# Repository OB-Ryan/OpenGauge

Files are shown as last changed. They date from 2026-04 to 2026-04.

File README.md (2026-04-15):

# OpenGauge
OpenGauge is an ESP32-based OBD-II CAN bus interface for reading real-time vehicle telemetry such as speed, engine RPM, and coolant temperature using an MCP2551 CAN transceiver.

## Components and Materials
- ESP32 Microcontroller
- 12V to 5V Buck Converter
- MCP2551 CAN Transceiver
- 5V 3.3V Bidirectional Logic Shifter
- 16x2 I2C LCD Display
- OBD-II Harness
- Push Button
- Breadboard
- Jumperwires
- Multimeter

## Circuit
### OBD-II Harness
The OBD-II harness will plug into the vehicle, and provide a means for interfacing with the vehicle ECU. The pins of interest are CAN High, CAN Low, Chasis ground, Signal ground, and +12V battery power. Double check the harness connetions with the corresponding pin numbers using a miltimeter.

### ESP32 and Components
This project uses an ESP32 development board as the primary microcontroller, connected to three 3 components:

CAN Bus Interface: The ESP32's built-in TWAI (Two-Wire Automotive Interface) is used for OBD-II communication. GPIO 4 (RX) and GPIO 5 (TX) connect to a MCP2551 CAN transceiver module, which interfaces with the vehicle's OBD-II diagnostic port. A 3.3V-5V logic shifter is placed between the transceiver and EPS32, to step up/down the voltage logic accordinly.

Display: A 16×2 LCD display (I2C address 0x27) connects via the ESP32's I2C bus to display the currently selected sensor reading and its value.

User Input: A momentary push button connected to GPIO 23, and ground (with internal pull-up enabled) allows the user to cycle through available sensor modes.

### Pictorial Schematic
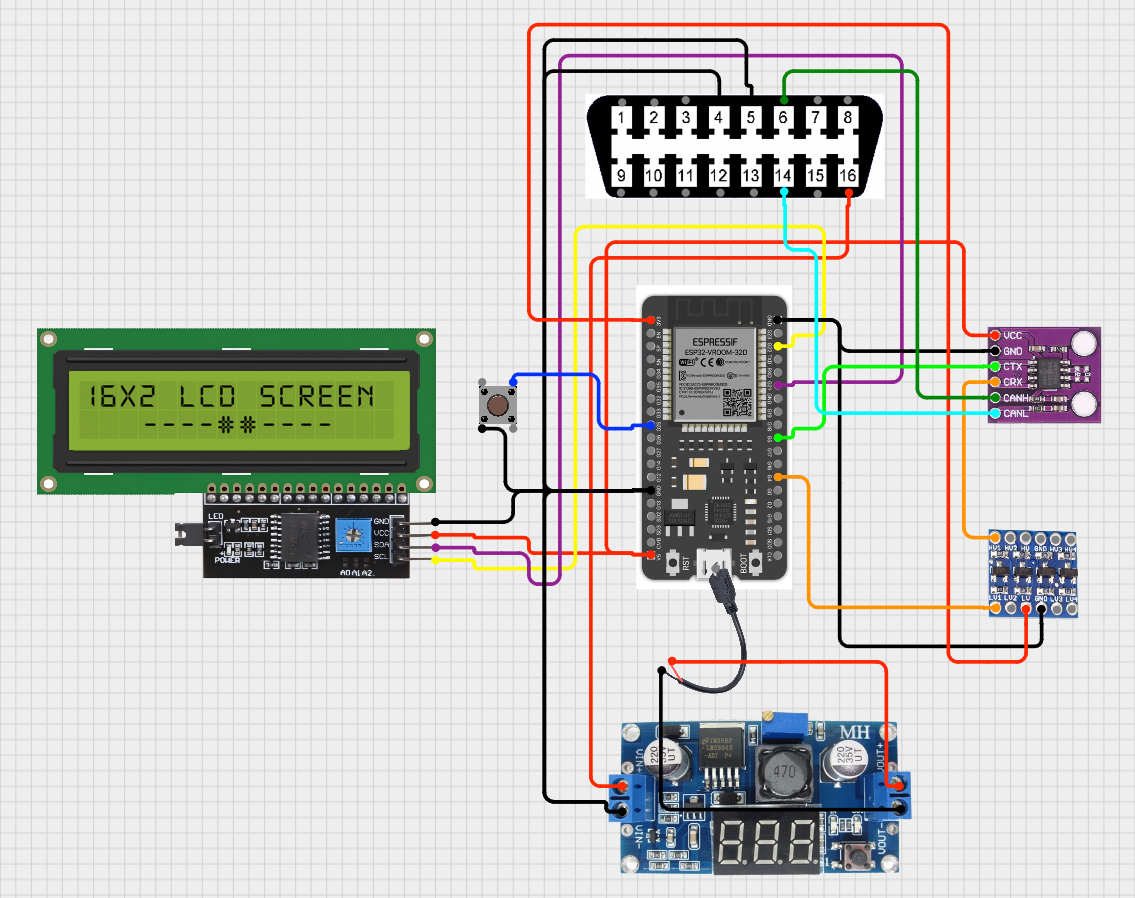
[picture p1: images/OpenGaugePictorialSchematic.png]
Pictorial Schematic


## Code
This project is implemented in Arduino C++ with PlatformIO for an ESP32-based OBD-II gauge. At a high level, main.cpp initializes the CAN interface and LCD display, then runs a simple state polling loop (IDLE and WAITING states) to request and display live vehicle data.

Using the [ESP32-TWAI-CAN library](https://github.com/handmade0octopus/ESP32-TWAI-CAN), the firmware periodically sends OBD-II Mode 01 requests for the currently selected PID. A push button cycles through these display modes, and the LCD is updated with the latest valid reading. Currently, the requested PIDs allow display modes of engine load, engine RPM, vehicle speed, coolant temperature, intake temperature, oil temperature, and fuel pressure.

The runtime logic is designed to be bus-friendly and resilient. Requests are limited to one every 1.2 seconds to avoid ECU-lockout, responses are validated by CAN ID/mode/PID before use, and timeout handling returns the system to request mode without blocking. If repeated transmit failures occur, CAN is marked offline and the code periodically attempts automatic bus recovery.

## PCB
A custom PCB has been designed to provide a more integrated solution. The board features soldered pads for the ESP32 microcontroller, MCP2551 CAN transceiver, logic level shifter, and user button.

Screw terminals provide connectors for the OBD-II diagnostic harness and I2C LCD display, and integrated mounting holes allow the buck converter and LCD to be secured directly to the board for a clean, compact layout. This design enables quick assembly for a more permanent design of this project.
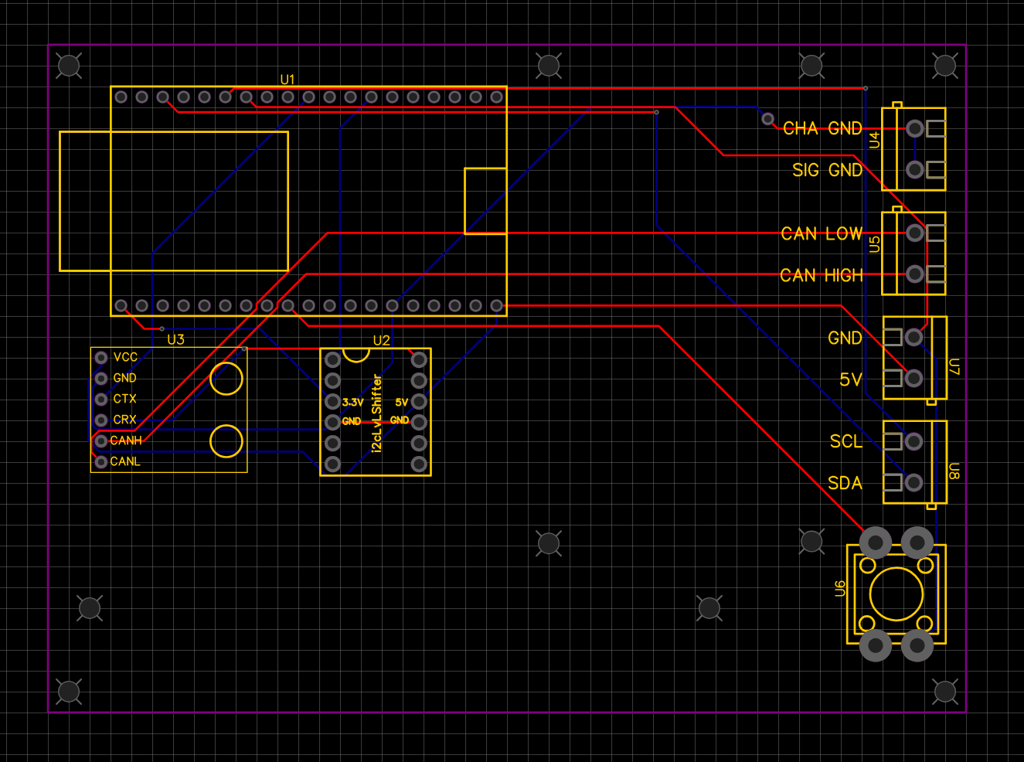
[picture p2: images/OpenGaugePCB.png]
PCB


PCB fabrication and source files are included in the `PCB/` directory:
- EasyEDA source: `PCB/OpenGauge.json`
- Manufacturing files: `PCB/OpenGauge_Gerber/`
- Ordering notes: `PCB/README.md`

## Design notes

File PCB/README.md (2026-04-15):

# OpenGauge PCB Files

This folder contains both the editable EasyEDA source and the manufacturing outputs needed to order boards.

## Contents
- `OpenGauge.json`: EasyEDA source file (edit this file for schematic/PCB changes)
- `OpenGauge_Gerber/`: Gerber and drill files for PCB fabrication

## Ordering a PCB
1. Zip the full `OpenGauge_Gerber/` folder.
2. Upload the zip to your PCB manufacturer (for example, JLCPCB, PCBWay, or OSH Park).
3. Verify board outline and drill preview before placing the order.

## Notes
- Keep all files inside `OpenGauge_Gerber/` together.
- Do not delete drill files (`.DRL`) or outline/layer files (`.GKO`, `.GTL`, `.GBL`, etc.).
- Regenerate and replace the Gerber folder any time the design in `OpenGauge.json` changes.

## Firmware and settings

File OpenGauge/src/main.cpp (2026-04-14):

#include <Arduino.h>
#include <ESP32-TWAI-CAN.hpp>
#include <LiquidCrystal_I2C.h>

/*
OBDII Reference: https://en.wikipedia.org/wiki/OBD-II_PIDs

    MODES
01  Show current data
02  Show freeze frame data
03  Show stored Diag trouble codes
04  Clear diag trouble codes and stored values
05  Test results, o2 sensor minitoring non-CAN
06  Test results, other component/system monitoring CAN
07  Show pending diag trouble codes
08  Control operation of on-board component/system
09  Request vehicle info
0A  Permanent Diag trouble codes

    STANDARD PIDs OF INTEREST
04  Calculated engine load (%). Formula: (A * 100) / 255
05  Engine coolant temperature (C). Formula: (A - 40)
10  Fuel pressure (kPa). Formula: A * 3
12  Engine speed (RPM). Formula: ((256A + B) / 4)
13  Vehicle speed (km/h). Formula: (A)
15  Intake air temperature (C). Formula: (A - 40)
92  Engine oil temperature (C). Formula: (A - 40)
*/

// PIDs
#define LOAD        4
#define COOLANT_TMP 5
#define FUEL_PRESS  10
#define RPM         12
#define SPEED       13
#define AIR_TMP     15
#define OIL_TMP     92

// Pin definitions and constants
#define CAN_TX		5               // CAN TX GPIO
#define CAN_RX		4               // CAN RX GPIO
#define I2C_ADDR  0x27            // I2C LCD addr
#define LCD_LINES 2               // 16x2 LCD screen size
#define LCD_LEN   16
#define BUTTON    23              // Push-button on pin 23
#define OBDII_RESPONSE_ID_MIN      0x7E8
#define OBDII_RESPONSE_ID_MAX      0x7EF
#define OBDII_REQUEST_IDENTIFIER   0x7DF

LiquidCrystal_I2C lcd(I2C_ADDR, 16, 2);
CanFrame rxFrame;
char buf[LCD_LEN + 1];  // Buffer to hold strings to print on LCD
int mode = 0;           // Current sensor mode
int modes[] = {LOAD, COOLANT_TMP, FUEL_PRESS, RPM, SPEED, AIR_TMP, OIL_TMP};
int mode_index = 0;
int num_modes = sizeof(modes) / sizeof(modes[0]);

// Sensor reading vars
int latest_load = -1;
int latest_coolant_temp = -1;
float latest_fuel_pressure = -1;
int latest_rpm = -1;
float latest_speed = -1;
int latest_air_temp = -1;
int latest_oil_temp = -1;

// State management
enum State {IDLE, WAITING};
State state = IDLE;
unsigned long request_sent_time = 0;
const unsigned long timeout = 1000;              // 1 second CAN request timeout
unsigned long last_obd_request_time = 0;
const unsigned long obd_request_interval = 1200; // 1.2 second between OBD requests (allow margin of error)

unsigned long last_invalid_frame_log_time = 0;
bool can_online = false;
int consecutive_tx_failures = 0;
const int failure_threshold = 10;
unsigned long last_recovery_attempt_time = 0;
const unsigned long recovery_interval = 3000;


bool is_obd_response_identifier(uint32_t identifier) {
  return identifier >= OBDII_RESPONSE_ID_MIN && identifier <= OBDII_RESPONSE_ID_MAX;
}

bool is_valid_obd_response(const CanFrame &frame, uint8_t expected_pid, uint8_t min_dlc) {
  return !frame.extd &&
    is_obd_response_identifier(frame.identifier) &&
    frame.data_length_code >= min_dlc &&
    frame.data[1] == 0x41 &&
    frame.data[2] == expected_pid;
}

void log_frame_brief(const CanFrame &frame) {
  Serial.printf("RX id=0x%03lX dlc=%d data=%02X %02X %02X %02X %02X %02X %02X %02X\n",
    frame.identifier,
    frame.data_length_code,
    frame.data[0],
    frame.data[1],
    frame.data[2],
    frame.data[3],
    frame.data[4],
    frame.data[5],
    frame.data[6],
    frame.data[7]
  );
}

bool begin_can() {
  bool success = ESP32Can.begin(ESP32Can.convertSpeed(500), CAN_TX, CAN_RX, 10, 10);
  if (success) {
    Serial.println("CAN bus started!");
  } else {
    Serial.println("CAN bus failed!");
  }
  return success;
}

bool send_obd_frame(uint8_t obdId) {
	CanFrame obdFrame = { 0 };
  obdFrame.identifier = OBDII_REQUEST_IDENTIFIER;
	obdFrame.extd = 0;
	obdFrame.data_length_code = 8;
	obdFrame.data[0] = 2;
	obdFrame.data[1] = 1;
	obdFrame.data[2] = obdId;
  
  // Padding of 0xAA to avoid bit surfing
  obdFrame.data[3] = 0xAA;
  obdFrame.data[4] = 0xAA;
  obdFrame.data[5] = 0xAA;
  obdFrame.data[6] = 0xAA;
	obdFrame.data[7] = 0xAA;

  // Accepts both pointers and references 
  bool tx_ok = ESP32Can.writeFrame(obdFrame, 25);
  if (!tx_ok) {
    Serial.printf("TX failed for PID 0x%02X\n", obdId);
    return false;
  } else {
    Serial.printf("TX PID 0x%02X on 0x%03X\n", obdId, OBDII_REQUEST_IDENTIFIER);
    return true;
  }
}

void init_lcd() {
  lcd.init();
  lcd.backlight();
  lcd.clear();
  lcd.setCursor(0, 0);
  lcd.print("OBD2 CAN Ready");
}

void lcd_clear_line(int line) {
  if (line != 0 && line != 1) {
    Serial.println("ERROR    |    lcd_clear_line: line not valid for 16x2 LCD");
    return;
  }

  lcd.setCursor(0, line);
  for (int i = 0; i < LCD_LEN; i++) {
    lcd.print(" ");
  }
}

void lcd_write(int line, const char* message) {
  if (line != 0 && line != 1) {
    Serial.println("ERROR    |    lcd_write: line not valid for 16x2 LCD");
    return;
  }

  if (strlen(message) > LCD_LEN) {
    Serial.println("ERROR    |    lcd_write: message too long for 16x2 LCD");
    return;
  }

  lcd_clear_line(line);
  lcd.setCursor(0, line);
  lcd.print(message);
}

bool process_load_response(const CanFrame &rxFrame) {
  if (is_valid_obd_response(rxFrame, LOAD, 4)) {
    latest_load = (rxFrame.data[3] * 100) / 255;
    Serial.printf("Load: %d%%\n", latest_load);
    snprintf(buf, sizeof(buf), " %d%% ", latest_load);
    lcd_write(1, buf);
    return true;
  }

  return false;
}

bool process_coolant_temp_response(const CanFrame &rxFrame) {
  if (is_valid_obd_response(rxFrame, COOLANT_TMP, 4)) {
    latest_coolant_temp = rxFrame.data[3] - 40;
    Serial.printf("Coolant temp: %d%c\n", latest_coolant_temp, (char)223);
    snprintf(buf, sizeof(buf), " %d%cC ", latest_coolant_temp, (char)223);
    lcd_write(1, buf);
    return true;
  }

  return false;
}

bool process_fuel_pressure_response(const CanFrame &rxFrame) {
  if (is_valid_obd_response(rxFrame, FUEL_PRESS, 4)) {
    latest_fuel_pressure = (rxFrame.data[3] * 3) * 0.1450377; // Convert kPa to PSI
    Serial.printf("Fuel pressure: %.2f PSI\n", latest_fuel_pressure);
    snprintf(buf, sizeof(buf), "    %.2f PSI", latest_fuel_pressure);
    lcd_write(1, buf);
    return true;
  }

  return false;
}

bool process_rpm_response(const CanFrame &rxFrame) {
  if (is_valid_obd_response(rxFrame, RPM, 5)) {
    latest_rpm = (((256 * rxFrame.data[3]) + rxFrame.data[4]) / 4);
    Serial.printf("RPM: %3d\n", latest_rpm);
    snprintf(buf, sizeof(buf), "    %d ", latest_rpm);
    lcd_write(1, buf);
    return true;
  }

  return false;
}

bool process_speed_response(const CanFrame &rxFrame) {
  if (is_valid_obd_response(rxFrame, SPEED, 4)) {
    latest_speed = (rxFrame.data[3] / 1.609344);  // Convert kph to mph
    Serial.printf("Speed: %.2f mph\n", latest_speed);
    snprintf(buf, sizeof(buf), "    %.2f mph", latest_speed);
    lcd_write(1, buf);
    return true;
  }

  return false;
}

bool process_air_temp_response(const CanFrame &rxFrame) {
  if (is_valid_obd_response(rxFrame, AIR_TMP, 4)) {
    latest_air_temp = rxFrame.data[3] - 40;
    Serial.printf("Intake air temp: %d%c\n", latest_air_temp, (char)223);
    snprintf(buf, sizeof(buf), "    %d%cC ", latest_air_temp, (char)223);
    lcd_write(1, buf);
    return true;
  }

  return false;
}

bool process_oil_temp_response(const CanFrame &rxFrame) {
  if (is_valid_obd_response(rxFrame, OIL_TMP, 4)) {
    latest_oil_temp = rxFrame.data[3] - 40;
    Serial.printf("Oil temp: %d%c\n", latest_oil_temp, (char)223);
    snprintf(buf, sizeof(buf), "    %d%cC ", latest_oil_temp, (char)223);
    lcd_write(1, buf);
    return true;
  }

  return false;
}

const char* mode_title(int current_mode) {
  switch (current_mode)
  {
  case LOAD:
    return "Engine Load";
  case COOLANT_TMP:
    return "Coolant Temp";
  case RPM:
    return "Engine RPM";
  case SPEED:
    return "Car Speed";
  case FUEL_PRESS:
    return "Fuel Pressure";
  case AIR_TMP:
    return "Intake Air Temp";
  case OIL_TMP:
    return "Oil Temp";
  default:
    return "Unknown Mode";
  }
}

void write_mode() {
  lcd_write(0, mode_title(mode));
}

bool process_response(const CanFrame &rxFrame) {
  switch (mode)
  {
  case LOAD:
    return process_load_response(rxFrame);
  case COOLANT_TMP:
    return process_coolant_temp_response(rxFrame);
  case RPM:
    return process_rpm_response(rxFrame);
  case SPEED:
    return process_speed_response(rxFrame);
  case FUEL_PRESS:
    return process_fuel_pressure_response(rxFrame);
  case AIR_TMP:
    return process_air_temp_response(rxFrame);
  case OIL_TMP:
    return process_oil_temp_response(rxFrame);
  default:
    return false;
  }
}

void button_update() {
  if (digitalRead(BUTTON) == LOW) {
    mode_index++;
    if (mode_index >= num_modes) {
      mode_index = 0;
    }
    mode = modes[mode_index];
    write_mode();
    delay(200); // debounce delay
  }
}

void setup() {
  Serial.begin(115200);

  // Set pins
	ESP32Can.setPins(CAN_TX, CAN_RX);
  pinMode(BUTTON, INPUT_PULLUP);
	
  // Set TX and RX queue sizes. Larger RX queue incase of busy bus
  ESP32Can.setRxQueueSize(64);
	ESP32Can.setTxQueueSize(5);

  can_online = begin_can();
  init_lcd();
  if (!can_online) {
    lcd_write(1, "No CAN bus");
  }

  // Set the mode. Default to first mode in list
  mode = modes[0];
  write_mode();
}

void loop() {
  // Polling button - cycle mode on press
  button_update();

  unsigned long now = millis();

  // Attempt recovery of CAN bus if offline
  if (!can_online) {
    if (now - last_recovery_attempt_time >= recovery_interval) {
      last_recovery_attempt_time = now;
      Serial.println("Attempting CAN recovery...");
      if (begin_can()) {
        can_online = true;
        consecutive_tx_failures = 0;
        state = IDLE;
        lcd_write(1, "CAN recovered");
      } else {
        lcd_write(1, "No CAN bus");
      }
    }
    return;
  }

  // Send request if idle. No more than 1 per second
  if (state == IDLE) {
    if (now - last_obd_request_time >= obd_request_interval) {
      last_obd_request_time = now;
      if (send_obd_frame(mode)) {
        consecutive_tx_failures = 0;
        request_sent_time = now;
        state = WAITING;
      } else {
        consecutive_tx_failures++;
        // Leave state IDLE so we can retry on next interval without waiting for response timeout.
        snprintf(buf, sizeof(buf), "TX failed %d", mode);
        lcd_write(1, buf);
        if (consecutive_tx_failures >= failure_threshold) {
          Serial.println("CAN marked offline after repeated TX failures");
          can_online = false;
          state = IDLE;
          lcd_write(1, "No CAN bus");
        }
      }
    }
  } else if (state == WAITING) {
    // Empty all queued frames and only leave WAITING when we find a matching OBD response.
    bool matched_response = false;
    while (ESP32Can.readFrame(rxFrame, 0)) {
      if (process_response(rxFrame)) {
        matched_response = true;
        break;
      }

      if (now - last_invalid_frame_log_time >= 250) {
        // Throttle logs so monitor stays readable
        log_frame_brief(rxFrame);
        last_invalid_frame_log_time = now;
      }
    }

    if (matched_response) {
      state = IDLE;
    } else if (now - request_sent_time > timeout) {
      // Timeout for CAN response. Set to idle to try again
      snprintf(buf, sizeof(buf), "No Resp PID %2d", mode);
      lcd_write(1, buf);
      Serial.println("Timeout waiting for matching OBD response");
      state = IDLE;
    }
  }
}

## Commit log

2026-04-14 Expand README with project details and instructions
    Added detailed project components, circuit description, code implementation, and PCB design information to the README.
2026-04-15 Added PCB files
    [Drill_NPTH_Through.DRL, Drill_PTH_Through.DRL, Drill_PTH_Through_Via.DRL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]
